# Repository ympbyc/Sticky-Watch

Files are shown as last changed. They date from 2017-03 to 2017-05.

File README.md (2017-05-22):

ISD1700 Fragmented Memory Manager
=================================

Arduino sketch that controls ISD1700 record/playback ic over SPI. It's packed with awesome features. Read on.

<!-- ![Test Setup](docs/test-setup.jpg?raw=true "Test Setup") -->
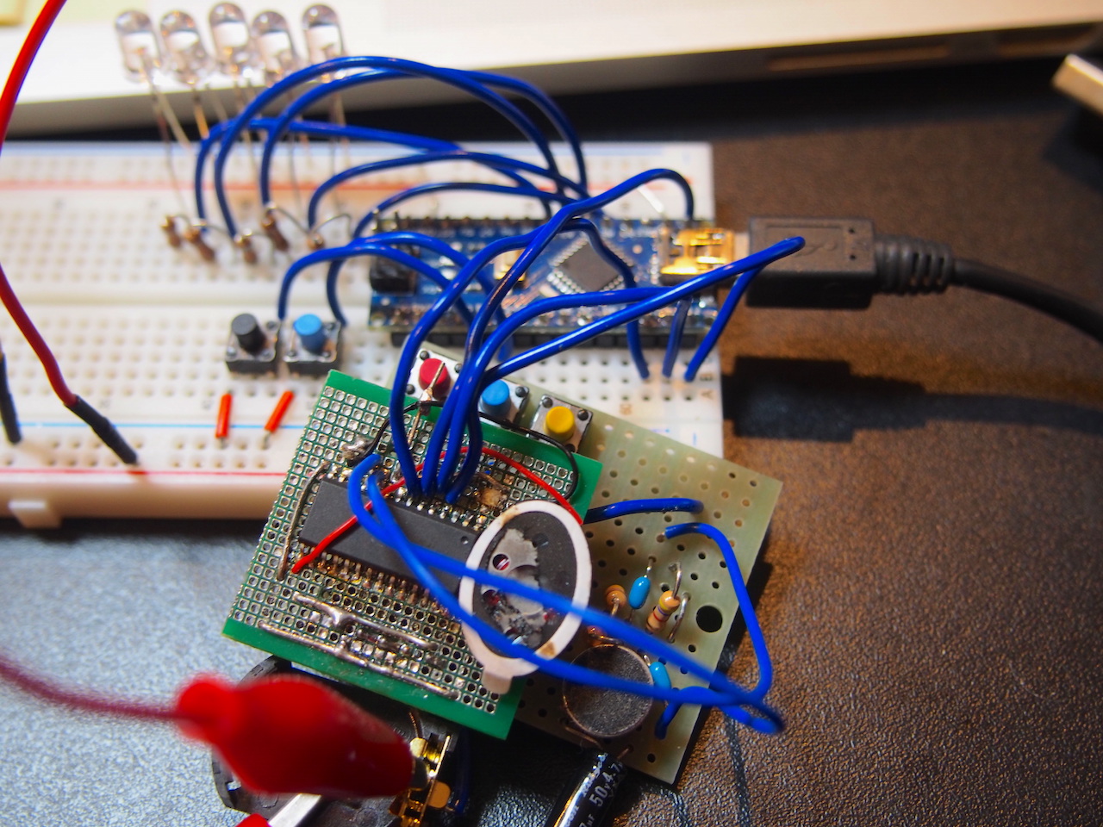
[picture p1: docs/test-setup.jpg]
Test Setup


Caution
-------

It's a WIP and a little buggy.

Features
--------

+ Fragmented memory management: divides the memory into N fixed-size randomly-accessible sections.
+ LED indicators: N LEDs can be attached to IO pins to indicate memory occupancy status and cursor position.
+ Multi-function buttons: Reduce the number of pushbuttons by utilizing single-click/double-click/long-press actions.
+ Sleep mode: Arduino enters SLEEP_MODE_PWR_DOWN after putting ISD1700 to power-down mode. Wakes up on button action and immediately executes the given command.

\* N being an integer

Default Setup
-------------

### Memory management

Address range is configured for ISD1790. Adjust LAST_ADDR macro value to match your chip. (Refer to ISD1700 Design Guide)

Number of sections the memory gets devided into is set by SLOT_NUM macro.

### APC register

By default the APC is setup to accept input from Mic. Change the APC macro value to match your need. (Refer to ISD1700 Design Guide)

### Push Buttons

#### MAIN_BTN

+ single-click: (play) play current section
+ long-press:   (rec)  start recording into first vacant section

#### SUB_BTN

+ single-click: forward
+ long-press:   erase current slot

### LEDs

+ ON when the section is occupied
+ OFF when the section is vacant
+ Blink to indicate current section (play, fwd, rec)

Default Wiring
--------------

| ISD1700 | Arduino |
| --- | --- |
| MISO | D12 |
| MOSI | D11 |
| SCLK | D13 |
| SS | D10 |

| Arduino | LED/BTN  |
| --- | --- |
| D14(A0) | LED0 |
| D15(A1) | LED1 |
| ... | LEDN-1 |
| D3 | MAIN_BTN |
| D2 | SUB_BTN  |

Schematic
---------

<!-- ![ISD1700 Schematic](docs/schematic-isd1700.jpg?raw=true "ISD1700 Schematic") -->
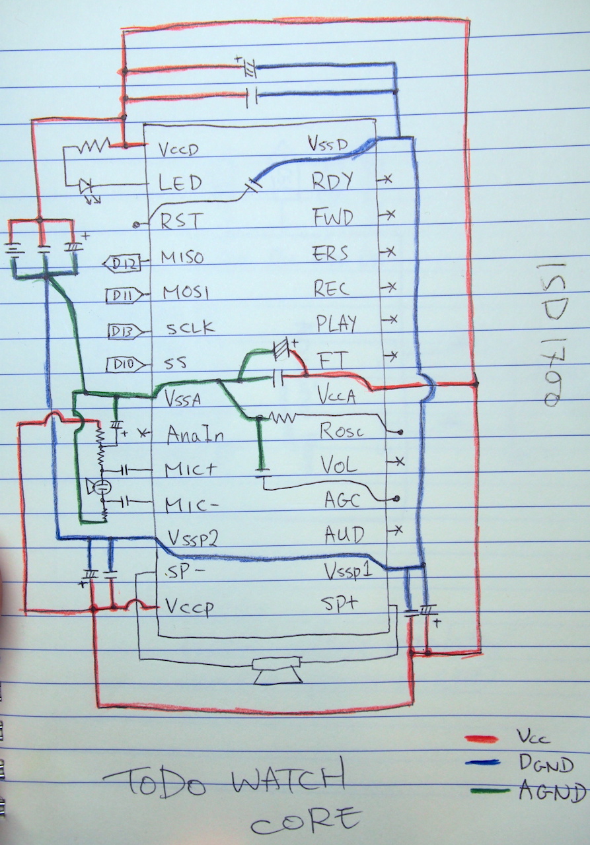
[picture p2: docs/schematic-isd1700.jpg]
ISD1700 Schematic

<!-- ![Arduino Schematic](docs/schematic-arduino.jpg?raw=true "Arduino Schematic") -->
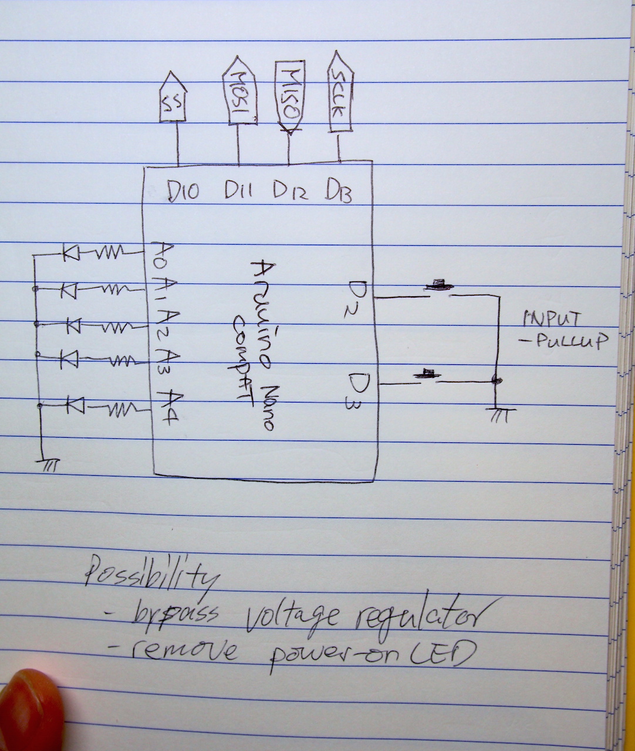
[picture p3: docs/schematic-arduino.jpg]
Arduino Schematic


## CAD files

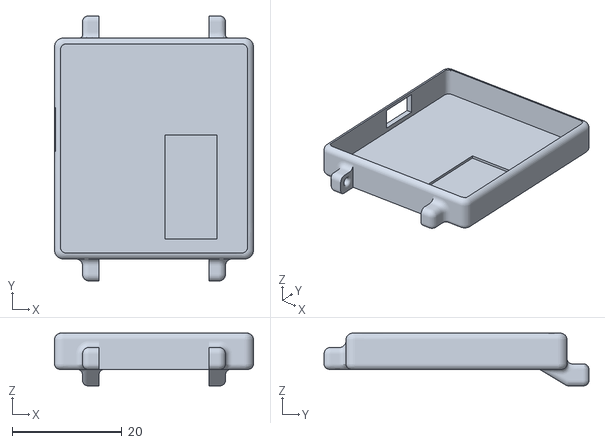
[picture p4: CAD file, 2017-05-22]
inner-case.stl
36.2 x 48.2 x 9.60

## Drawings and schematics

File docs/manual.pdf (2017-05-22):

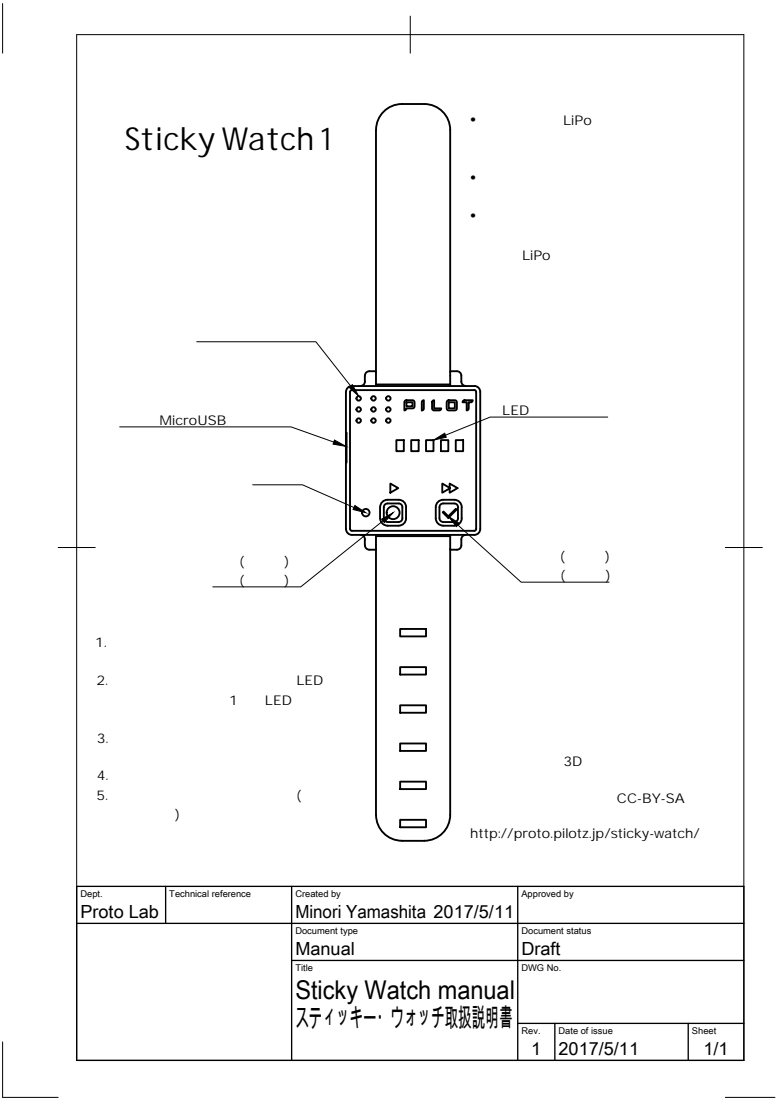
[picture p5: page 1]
録音(長押し) 再生(単押し); 右ボタン; • 本製品はLiPo電池を内蔵していま; る場所に放置しないでください •; 水濡れを避けてください。万一濡れ; た場合は分解して乾かしてください •; 電池が完全に水につかるなどした場; 1. 左ボタンを長押しします。録音が; 2. メモリーに空きがあれば、LED ディスプレイの1つのLEDが点滅し; 3. 点滅が開始したら録音してくださ; 4. 録音が終わったら指を離します。 5. 同じボタンを一瞬だけ押す(クリッ

消去(長押し) 次へ(単押し)

本製品はオープンソースハードウェアです。
回路図やファームウェアのソースコード、
プリント可能な3Dモデル、修理のしかたな
どは以下のウェブサイトからご確認いただけ
ます。ライセンスは全てCC-BY-SAです。

http://proto.pilotz.jp/sticky-watch/

Dept. Proto Lab | Technical reference | Created by Minori Yamashita 2017/5/11 | Approved by

Document type Manual | Document status Draft

Title Sticky Watch manual スティッキー・ウォッチ取扱説明書 | DWG No.

Rev. 1 | Date of issue 2017/5/11 | Sheet 1/1

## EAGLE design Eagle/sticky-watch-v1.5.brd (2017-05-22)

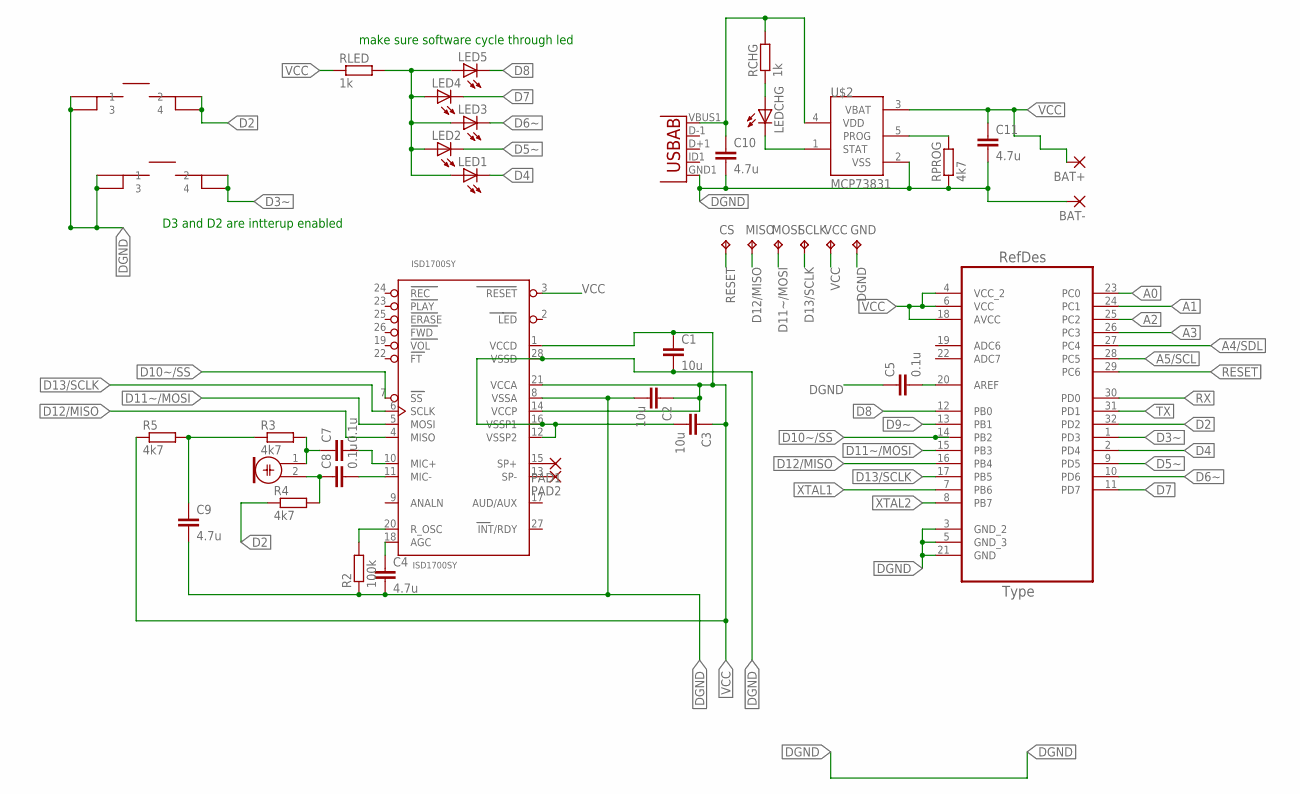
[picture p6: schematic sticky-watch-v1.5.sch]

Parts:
BAT+: 1,6/0,8
BAT-: 1,6/0,8
C1, C2, C3: 10u; C0603
C4, C9, C10, C11: 4.7u; C0603
C5, C7, C8: 0.1u; C0603
CS: TPTP10R; TP10R
GND: TPTP10R; TP10R
ISD1700SY: ISD1700SY; SO28W
LED1, LED2, LED3, LED4, LED5: LEDSML0805; SML0805
LEDCHG: LEDSML0805; SML0805
M1: ELECTRET_MICROPHON-WM-63PR; WM-63PR
MISO: TPTP10R; TP10R
MOSI: TPTP10R; TP10R
PAD1, PAD2: 1,6/0,8
R2: 100k; R0603
R3, R4, R5: 4k7; R0603
RCHG: 1k; R0603
RLED: 1k; R0603
RPROG: 4k7; R0603
S1: 0; SMD-TACT-5.2MM
S2: SMD-TACT; SMD-TACT-5.2MM
SCLK: TPTP10R; TP10R
U1: ATMEGA328P-AU; QFP80P900X900X120-32N
U2: USB""; USB-MICRO-SMD
U$2: MCP73831; SOT23-5L
VCC: TPTP10R; TP10R

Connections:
A0: U1.23 (PC0)
A1: U1.24 (PC1)
A2: U1.25 (PC2)
A3: U1.26 (PC3)
A4/SDL: U1.27 (PC4)
A5/SCL: U1.28 (PC5)
D2: R4.1, S2.2, S2.4, U1.32 (PD2)
D3~: S1.2, S1.4, U1.1 (PD3)
D4: LED1.C, U1.2 (PD4)
D5~: LED2.C, U1.9 (PD5)
D6~: LED3.C, U1.10 (PD6)
D7: LED4.C, U1.11 (PD7)
D8: LED5.C, U1.12 (PB0)
D9~: U1.13 (PB1)
D10~/SS: ISD1700SY.7 (SS), U1.14 (PB2)
D11~/MOSI: ISD1700SY.5 (MOSI), MOSI.TP, U1.15 (PB3)
D12/MISO: ISD1700SY.4 (MISO), MISO.TP, U1.16 (PB4)
D13/SCLK: ISD1700SY.6 (SCLK), SCLK.TP, U1.17 (PB5)
DGND: BAT-.1, C1.2, C2.2, C3.2, C4.2, C5.1, C9.2, C10.2, C11.2, GND.TP, ISD1700SY.8 (VSSA), ISD1700SY.12 (VSSP2), ISD1700SY.16 (VSSP1), ISD1700SY.28 (VSSD), R2.1, RPROG.1, S1.1, S1.3, S2.1, S2.3, U1.3 (GND_2), U1.5 (GND_3), U1.21 (GND), U2.GND1 (GND), U$2.2 (VSS)
unnamed: LED1.A, LED2.A, LED3.A, LED4.A, LED5.A, RLED.2
unnamed: C10.1, RCHG.2, U2.VBUS1 (VBUS), U$2.4 (VDD)
unnamed: ISD1700SY.15 (SP+), PAD1.1
unnamed: LEDCHG.A, RCHG.1
unnamed: C7.2, ISD1700SY.10 (MIC+)
unnamed: LEDCHG.C, U$2.1 (STAT)
unnamed: C5.2, U1.20 (AREF)
unnamed: ISD1700SY.13 (SP-), PAD2.1
unnamed: C4.1, ISD1700SY.18 (AGC)
unnamed: ISD1700SY.20 (R_OSC), R2.2
unnamed: C8.2, ISD1700SY.11 (MIC-)
unnamed: C8.1, M1.2, R4.2
unnamed: RPROG.2, U$2.5 (PROG)
unnamed: C9.1, R3.1, R5.2
unnamed: C7.1, M1.1, R3.2
RESET: CS.TP, U1.29 (PC6)
RX: U1.30 (PD0)
TX: U1.31 (PD1)
VCC: BAT+.1, C1.1, C2.1, C3.1, C11.1, ISD1700SY.1 (VCCD), ISD1700SY.3 (RESET), ISD1700SY.14 (VCCP), ISD1700SY.21 (VCCA), R5.1, RLED.1, U1.4 (VCC_2), U1.6 (VCC), U1.18 (AVCC), U$2.3 (VBAT), VCC.TP
XTAL1: U1.7 (PB6)
XTAL2: U1.8 (PB7)

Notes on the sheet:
make sure software cycle through led
D3 and D2 are intterup enabled

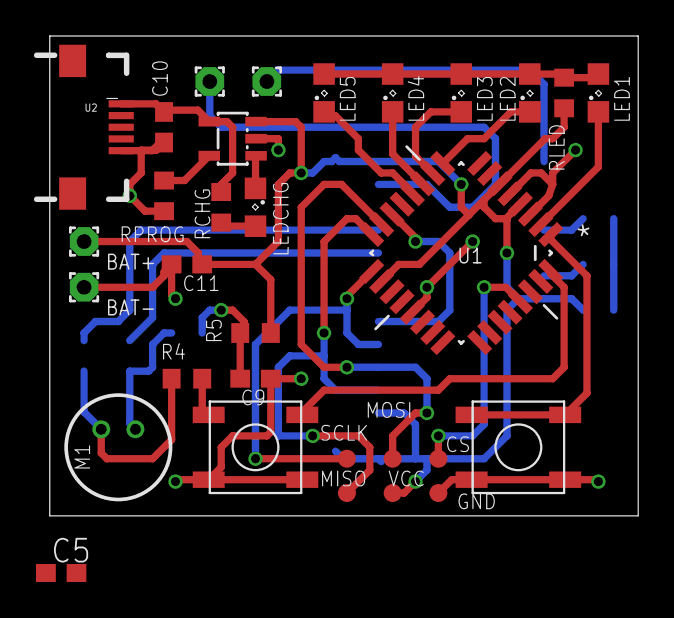
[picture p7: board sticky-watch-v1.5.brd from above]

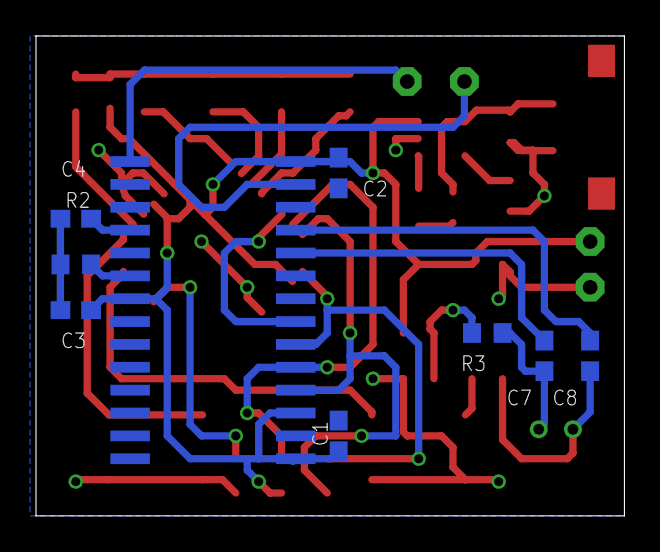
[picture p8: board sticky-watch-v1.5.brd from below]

Board: 2 copper layers, 32.7 x 26.7 mm, 40 parts (9 on the bottom side), 29 nets.

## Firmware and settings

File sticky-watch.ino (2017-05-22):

/*
 * ISD1700 Manager sketch
 * Author: Minori Yamashita
 * Contact: ympbyc@gmail.com
 * 
 * Thanks! to following library authors:
 * ISD1700 lib by neuron_upheaval https://forum.arduino.cc/index.php?topic=52509.0
 * Timer lib by Simon Monk http://playground.arduino.cc/Code/Timer
 * OneButton lib by Matthias Hertel http://www.mathertel.de/Arduino/OneButtonLibrary.aspx
 */

#include <avr/interrupt.h>
#include <avr/power.h>
#include <avr/sleep.h>
#include <avr/io.h>
#include <EEPROM.h>
#include <ISD1700.h>
#include <OneButton.h>
#include <Timer.h>
#include <MsTimer2.h>

#define SS 10
#define FIRST_ADDR 0x010
#define LAST_ADDR 0x3cf //3cf for 120, 2df for 90
#define APC 0xE1 //000011100001
#define SLOT_NUM 5

#define MAIN_BTN 3 //3
#define SUB_BTN  2 //2

#define LEDI 4 //1 for D1, 14 for A0
#define LEDN 5
#define LEDFREQ 100
#define LEDREP 5

#define REC_TIMEUP ((120 * 1000) / SLOT_NUM)
#define AVR_PWR_DWN_TIME 3000

/*int digitalPinToInterrupt (int d) {
  if (d == 2) return 0;
  if (d == 3) return 1;
  return -1;
}*/

int interrupt_main_btn = digitalPinToInterrupt(MAIN_BTN);
int interrupt_sub_btn = digitalPinToInterrupt(SUB_BTN);

ISD1700 chip(SS); // Initialize chipcorder with
                 // SS at Arduino's digital pin 10

OneButton btn(SUB_BTN, true);
OneButton btn2(MAIN_BTN, true);

Timer tim;
int tim_id;
int c_w_t_id;
int r_tu_t_id;
int avr_pd_t_id;

uint16_t apc = 0;

uint16_t slot_addrs[SLOT_NUM];
uint16_t end_addrs[SLOT_NUM];
int cur_slot = 0;
int slot_occup[SLOT_NUM];

bool recording = false;

void setup() {
  int i;
  analogReference(INTERNAL);
  Serial.begin(115200);
  /* lower power consumption */
  DDRD &= B00000011;       // set Arduino pins 2 to 7 as inputs
  DDRB = B00000000;        // set pins 8 to 13 as inputs
  PORTD |= B11111100;      // enable pullups on pins 2 to 7
  PORTB |= B11111111;      // enable pullups on pins 8 to 13
  
  // re-set pin-mode for SPI after above setting
  pinMode(SCK_PIN, OUTPUT);
  pinMode(MOSI_PIN, OUTPUT);
  pinMode(MISO_PIN, INPUT);
  pinMode(SS, OUTPUT);

  for (i=LEDI; i<LEDI+LEDN; i++)
    pinMode(i, OUTPUT);
  pinMode(MAIN_BTN, INPUT_PULLUP);
  pinMode(SUB_BTN, INPUT_PULLUP);

  btn.setClickTicks(300);
  btn.setPressTicks(400);
  btn2.setClickTicks(300);
  btn2.setPressTicks(1500); //press longer for erase
  btn.attachClick(playback);
  btn.attachLongPressStart(rec);
  btn.attachLongPressStop(rec_end);
  btn2.attachClick(forward);
  btn2.attachLongPressStart(erase_one);
  digitalWrite(SS, HIGH); // just to ensure
  while (!chip_wakeup())
    delay(10);
  if (chip.PU()) {
    Serial.print(chip.CMD_ERR());
    Serial.print(chip.RDY());
    Serial.println("Chip woke up!");
  }
  apc |= APC;
  chip.wr_apc2(apc);
  check_chip_err();
    
  /*chip.g_erase();
  for (i=0; i<SLOT_NUM; i++)
    EEPROM[i] = 0;
  check_chip_err();*/

  sync_eeprom();
  
  MsTimer2::set(4, led_update);
  MsTimer2::start();

  //setup memory management
  for (i=0; i<SLOT_NUM; i++) {
    slot_addrs[i] = floor((LAST_ADDR - FIRST_ADDR) / SLOT_NUM) * i + FIRST_ADDR + i;
    end_addrs[i] = floor((LAST_ADDR - FIRST_ADDR) / SLOT_NUM) * (i+1) + FIRST_ADDR + i;
    Serial.println(slot_addrs[i], HEX);
  }

  chip.pd();
  //avr_sleep();
}

void sync_eeprom () {
  int i;
  for (i=0; i<SLOT_NUM; i++)
    slot_occup[i] = EEPROM[i];  //sync eeprom status with array
}

bool chip_wakeup () {
  // Power Up
  tim.stop(avr_pd_t_id); //clear pwrdwn timeout
  Serial.println("ISD1700 wakeup");
  chip.rd_status();
  if (chip.CMD_ERR()) { Serial.println("rd_status CMD_ERR"); }
  if (! chip.PU()) { Serial.println("instructing pu");  chip.pu();}
  delay(10);
  chip.stop(); //stop whatever it's doing
  chip.clr_int();
  if (chip.RDY()) return true;
  chip.reset();
  delay(100);
  if (chip.RDY()) return true;
  led_notwakeup_pattern();
  return false;
}

bool chip_cleanup () {
  tim.stop(c_w_t_id);
  Serial.print("Status---> ");
  Serial.print(chip.CMD_ERR()? "CMD_ERR ": " ");
  Serial.print(chip.PU()? "PU ": " ");
  Serial.print(chip.RDY()? "RDY ": "Not_RDY");
  Serial.println();
  c_w_t_id = tim.every(1000, attempt_pd);
}

void attempt_pd () {
  chip.rd_status();
  if (chip.INT() || chip.EOM()) {
    tim.stop(c_w_t_id);
    //chip.clr_int();
    chip.pd();
    Serial.println(chip.CMD_ERR() ? "pd CMD_ERR" : "ISD1700 powerdown");
    avr_pd_t_id = tim.after(AVR_PWR_DWN_TIME, avr_sleep);
  }
}

void playback () {
  Serial.println("button action: playback");
  if ( ! slot_occup[cur_slot]) return;
  if ( ! chip_wakeup()) return;
  chip.set_play(slot_addrs[cur_slot], end_addrs[cur_slot]);
  if (check_chip_err()) return;
  register_led_oscillation(cur_slot, LEDFREQ);
  tim_id = tim.after(5000, cancel_led_oscillation);
  chip_cleanup();
}

void forward () {
  Serial.println("button action: forward");
  if ( ! chip_wakeup()) return;
  chip.stop();
  //chip.fwd();
  cur_slot = next_occupied_slot(cur_slot);
  if (cur_slot == 0 && ! slot_occup[cur_slot]) return; //no recording
  chip.set_play(slot_addrs[cur_slot], end_addrs[cur_slot]);
  if (check_chip_err()) return;
  register_led_oscillation(cur_slot, LEDFREQ);
  tim_id = tim.after(5000, cancel_led_oscillation);
  chip_cleanup();
}

void write_eeprom (int i, byte x) {
  EEPROM.write(i, x);
  slot_occup[i] = x;
  tim.stop(tim_id);
  cancel_led_oscillation();
}

void rec () {
  Serial.println("button action: rec");
  int next_slot;
  if ( ! chip_wakeup()) return;
  next_slot = next_available_slot(cur_slot);
  if (next_slot < 0) return;
  recording = true;
  chip.set_rec(slot_addrs[next_slot], end_addrs[next_slot]);
  write_eeprom(next_slot, 1);
  register_led_oscillation(next_slot, LEDFREQ);
  cur_slot = next_slot;
  r_tu_t_id = tim.after(REC_TIMEUP, rec_end); //ensure rec_end gets called
}

void rec_end () {
  if (! recording) return;
  recording = false;
  Serial.println("rec end");
  cancel_led_oscillation();
  tim.stop(r_tu_t_id);
  delay(10);
  if (check_chip_err()) return;
  chip.stop();
  chip_cleanup();
}

void erase_one () {
  if ( ! chip_wakeup()) return;
  chip.set_erase(slot_addrs[cur_slot], end_addrs[cur_slot]);
  delay(10);
  //if (check_chip_err()) return;
  write_eeprom(cur_slot, 0);
  cur_slot = next_occupied_slot(cur_slot);
  chip_cleanup();
}

void erase_all () {
  int i;
  if ( ! chip_wakeup()) return;
  chip.g_erase();
  delay(10);
  if (check_chip_err()) return;
  for (i=0; i<SLOT_NUM; i++)
    write_eeprom(i, 0);
  cur_slot = 0;
  chip_cleanup();
}

//interrupt function
int rom_i = 0;
int led_i_max = LEDI+(LEDN-1);
volatile int osc_i = -1;
volatile int osc_st = 0;
void led_update () {
  //led display update LOW = ON
  if (rom_i > SLOT_NUM-1) {
    rom_i = 0;
    digitalWrite(led_i_max, HIGH);
  } else {
    digitalWrite(LEDI+rom_i - 1, HIGH);
  }
  
  //osc
  if (rom_i == osc_i) {
    digitalWrite(LEDI+rom_i, !osc_st);
    osc_st = !osc_st;
  }
  //slot occupation indication
  else if (slot_occup[rom_i])
    digitalWrite(LEDI+rom_i, LOW);
  else
    digitalWrite(LEDI+rom_i, HIGH);
  rom_i++;
}

void register_led_oscillation (int rom_i, int freq) {
  tim.stop(tim_id);
  osc_i = rom_i;
}

void cancel_led_oscillation () {
  osc_i = -1;
}

bool check_chip_err () {
  if (! chip.CMD_ERR()) return false;
  error_pattern();
  return true;
}

void led_off () {
  int i;
  MsTimer2::stop();
  for (i=0; i<SLOT_NUM; i++)
    digitalWrite(LEDI+i, HIGH);
}

void error_pattern () {
  int i;
  for (i=0; i < SLOT_NUM; i++)
    slot_occup[i] = 1; //enable all leds
  MsTimer2::stop();
  cancel_led_oscillation();
  MsTimer2::set(300, led_update);
  MsTimer2::start();
  delay(1000);
  sync_eeprom(); //restore slot occupation status
  MsTimer2::stop();
  MsTimer2::set(4, led_update);
  MsTimer2::start();
}

void led_notwakeup_pattern () {
  error_pattern();
}

int next_available_slot (int cur) {
  for (int i=0; i<SLOT_NUM; i++) {
    if ( ! slot_occup[i]) return i;
  }
  return -1;
}

int next_occupied_slot (int cur) {
  int nxt = (cur + 1) % SLOT_NUM;
  for (int i=nxt; i<SLOT_NUM+nxt; i++) {
    if (slot_occup[i % SLOT_NUM]) return i % SLOT_NUM;
  }
  return 0;
}

void pinInterrupt () {
  sleep_disable(); //Wait for an interrupt, disable, and continue
  detachInterrupt(interrupt_main_btn);
  detachInterrupt(interrupt_sub_btn);
}

void avr_sleep () {
  Serial.println("avr_sleep reached");
  if (digitalRead(MAIN_BTN) == LOW || digitalRead(SUB_BTN) == LOW) return;
  sleep_enable();  //Set sleep enable (SE) bit
  attachInterrupt(interrupt_main_btn, pinInterrupt, LOW);
  attachInterrupt(interrupt_sub_btn,  pinInterrupt, LOW);
  delay(100);
  set_sleep_mode(SLEEP_MODE_PWR_DOWN);
  led_off();
  Serial.println("Arduino PWR_DOWN");
  delay(10);
  sleep_mode();    //Put the device to sleep
  
  sleep_disable(); //Wait for an interrupt, disable, and continue
  Serial.println("Arduino Wakeup");
  sync_eeprom();
  MsTimer2::set(4, led_update);
  MsTimer2::start();
}

/* 
 * Secret Arduino Voltmeter – Measure Battery Voltage 
 * https://provideyourown.com/2012/secret-arduino-voltmeter-measure-battery-voltage/
 */
long readVcc() {
  // Read 1.1V reference against AVcc
  // set the reference to Vcc and the measurement to the internal 1.1V reference
  #if defined(__AVR_ATmega32U4__) || defined(__AVR_ATmega1280__) || defined(__AVR_ATmega2560__)
    ADMUX = _BV(REFS0) | _BV(MUX4) | _BV(MUX3) | _BV(MUX2) | _BV(MUX1);
  #elif defined (__AVR_ATtiny24__) || defined(__AVR_ATtiny44__) || defined(__AVR_ATtiny84__)
    ADMUX = _BV(MUX5) | _BV(MUX0);
  #elif defined (__AVR_ATtiny25__) || defined(__AVR_ATtiny45__) || defined(__AVR_ATtiny85__)
    ADMUX = _BV(MUX3) | _BV(MUX2);
  #else
    ADMUX = _BV(REFS0) | _BV(MUX3) | _BV(MUX2) | _BV(MUX1);
  #endif  

  delay(2); // Wait for Vref to settle
  ADCSRA |= _BV(ADSC); // Start conversion
  while (bit_is_set(ADCSRA,ADSC)); // measuring

  uint8_t low  = ADCL; // must read ADCL first - it then locks ADCH  
  uint8_t high = ADCH; // unlocks both

  long result = (high<<8) | low;

  result = 1125300L / result; // Calculate Vcc (in mV); 1125300 = 1.1*1023*1000
  return result; // Vcc in millivolts
}

//monitor vcc for LiPo protection
void pd_if_low_battery () {
  if (readVcc() < 2900) {
    chip.pd();
    delay(10);
    avr_sleep();
  }
}

void loop() {
  pd_if_low_battery(); 
  btn.tick();
  btn2.tick();
  tim.update();
  delay(10);
}
